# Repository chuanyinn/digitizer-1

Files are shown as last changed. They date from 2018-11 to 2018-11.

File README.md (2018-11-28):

# Digitzer
[Hardware](https://github.com/nupole/digitizer/tree/rev/hw) and [firmware](https://github.com/nupole/digitizer/tree/rev/fw) prototyping of a multichannel 8-bit, 100 MS/s digitizer.

## Features
- Two 1 V<sub>pp</sub> single-ended input channels
- Analog band-pass of 10 kHz to 10 MHz
- 8-bit, 100 MS/s ADCs
- Reconfigurable FPGAa
 - 1 kB/channel event buffer
 - Programmable pre and post-trigger sizes (0 to 2.55 &mu;s)
 - Programmable channel trigger thresholds
 - Programmable coincidence window sizes (0 to 2.55 &mu;s)
 - Programmable trigger coincidence value
 - Programmable trigger veto window size (0 to 2.55 &mu;s)
 - 32 I/O connections
 - 1 single-ended coax I/O
 - 4 JTAG connections

## Table of Contents
1. [Features](#features)
2. [Overview](#overview)

## Overview
The digitizer is a 100 mm by 50 mm electronics card with two 1 V<sub>pp</sub> single-ended input channels sampled by an 8-bit, 100 MS/s ADC. Each channels incoming data is written into its own circular buffer, and upon an internal trigger, is block transferred into its own 1 kB event buffer using user-defined pre and post-trigger window sizes ranging from 0 to 2.55 microseconds (0 to 255 bytes respectively). The event buffers are then readout on a parallel backplane interface.

To form an internal coincidence trigger, each input channel generates a user-defined coincidence window (ranging in size from 0 to 2.55 microseconds) by comparing the current ADC sample with a user-defined threshold. These coincidence windows are added and compared with a user-defined coincidence value to generate both a trigger and veto window. The veto window has user-defined size ranging from 0 to 2.55 microseconds and prevents a re-trigger during its duration.

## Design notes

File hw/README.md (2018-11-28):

# Digitizer (Hardware)
[Hardware](https://github.com/nupole/digitizer/tree/rev/hw) prototyping of a multichannel 8-bit, 100 MS/s digitizer.

## Features
 - Two singled ended input channels
 - Low-pass filter designed using current feedback amplifier in a Sallen-Key topology
 - 8-bit, 100 MS/s ADCs
 - Reconfigurable FPGA
  - 32 I/O connections
  - 1 single-ended coax I/O
  - 4 JTAG connections

## Modifications for Rev 0.1
 - [ ] Remove the solder mask covering the analog and trigger inputs
 - [ ] Exchange 4 pin header for a 6 pin header to include 3.3 V and GND from JTAG programmer
 - [ ] Copper fill the entire power plane
 - [ ] Add grounding strips on the front and back copper layers
 - [ ] Remove unused copper trace on the back copper layers
 - [ ] Slow the TCLK from FT232H programmer by bypassing to ground with 10's of pF

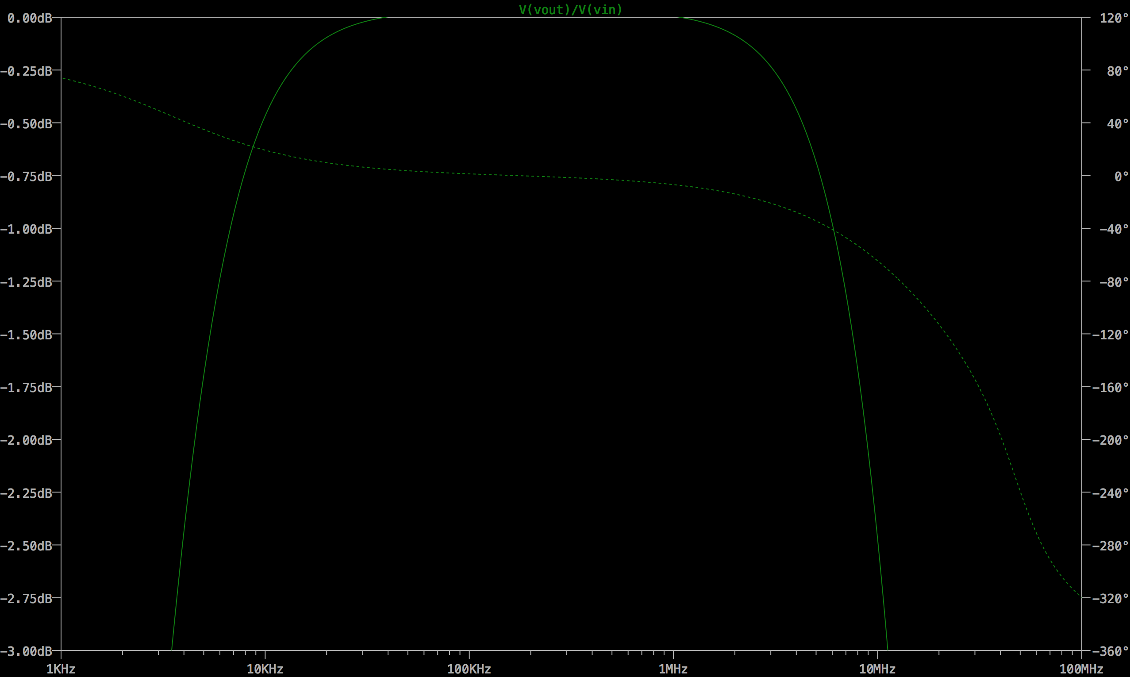
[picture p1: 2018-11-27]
hw/docs/images/Digitizer_AFE_Bandwidth.png

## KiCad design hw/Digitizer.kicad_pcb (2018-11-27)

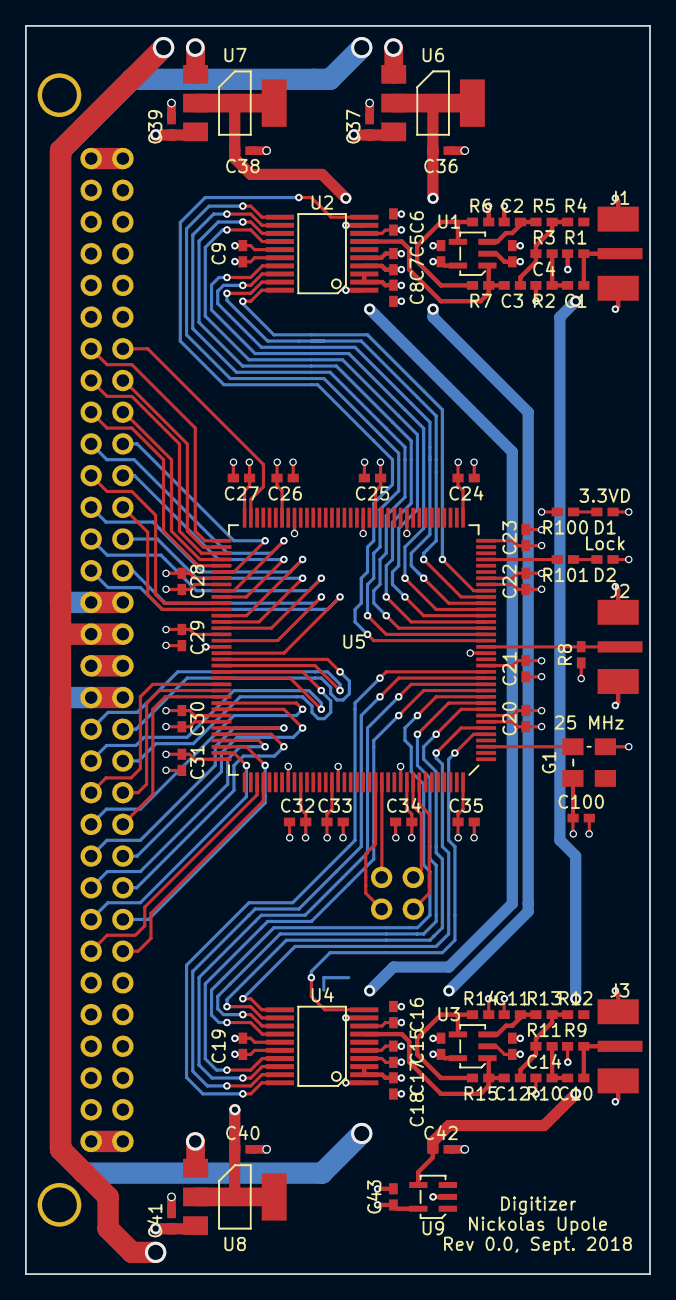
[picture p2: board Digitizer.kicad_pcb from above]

Board: 4 copper layers, 50.0 x 100.0 mm, 77 parts (0 on the bottom side), 81 nets.

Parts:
C1, C10: 1u; 0402
C2, C3, C4, C5, C6, C7, C8, C9, C11, C12, C14, C15, C16, C17, C18, C19, C20, C21, C22, C23, C24, C25, C26, C27, C28, C29, C30, C31, C32, C33, C34, C35, C36, C37, C38, C39, C40, C41, C42, C43, C100: C; 0402
D1, D2: LED; 0402
G1: 510CBA25M0000BAGR; OSC
J1, J2, J3: SMA
J7: Conn_x4; Conn_x4_Straight
J10: Conn_x64; Conn_x64_RightAngle
R1, R2, R8, R9, R10: 50; 0402
R3, R4, R5, R6, R7, R11, R12, R13, R14, R15, R100, R101: R; 0402
U1, U3: AD8014; SOT-23-5
U2, U4: AD9283; SSOP-20
U5: MachXO2; TQFP-144
U6, U7, U8: NCP1117; SOT-223
U9: MIC5270; SOT-23-5

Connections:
/3.3VA: C6.1, C7.1, C16.1, C17.1, C38.1, U2.5, U2.8, U4.5, U4.8, U7.2
/3.3VD: C9.2, C19.2, C20.1, C21.1, C22.1, C23.1, C24.1, C25.1, C26.1, C27.1, C28.2, C29.2, C30.2, C31.2, C32.2, C33.2, C34.2, C35.2, C40.1, C100.1, D1.2, G1.4, U2.15, U4.15, U5.7, U5.16, U5.30, U5.36, U5.37, U5.51, U5.66, U5.72, U5.79, U5.88, U5.102, U5.108, U5.118, U5.123, U5.135, U5.144, U8.2
/5V: C39.1, C41.1, J10.17, J10.48, U7.3, U8.3
/5VA: C5.1, C15.1, C36.1, U1.5, U3.5, U6.2
/12V: C37.1, J10.18, J10.47, U6.3
/25MHz: G1.3, U5.3
/-5VA: C4.2, C14.2, C42.2, U1.2, U3.2, U9.4
/-12V: C43.2, J10.15, J10.50, U9.5
/BP_D0: J10.39, U5.71
/BP_D1: J10.40, U5.74
/BP_D2: J10.41, U5.76
/BP_D3: J10.42, U5.78
/BP_D4: J10.43, U5.82
/BP_D5: J10.44, U5.84
/BP_D6: J10.45, U5.86
/BP_D7: J10.46, U5.89
/BP_D8: J10.51, U5.92
/BP_D9: J10.52, U5.94
/BP_D10: J10.53, U5.97
/BP_D11: J10.54, U5.98
/BP_D12: J10.55, U5.100
/BP_D13: J10.56, U5.104
/BP_D14: J10.57, U5.106
/BP_D15: J10.58, U5.112
/GND: C2.2, C4.1, C5.2, C6.2, C7.2, C8.2, C9.1, C11.2, C14.1, C15.2, C16.2, C17.2, C18.2, C19.1, C20.2, C21.2, C22.2, C23.2, C24.2, C25.2, C26.2, C27.2, C28.1, C29.1, C30.1, C31.1, C32.1, C33.1, C34.1, C35.1, C36.2, C37.2, C38.2, C39.2, C40.2, C41.2, C42.1, C43.1, C100.2, D2.1, G1.2, J1.1, J1.3, J1.4, J1.5, J2.1, J2.3, J2.4, J2.5, J3.1, J3.3, J3.4, J3.5, J10.1, J10.16, J10.32, J10.33, J10.49, J10.64, R1.2, R2.2, R6.1, R8.2, R9.2, R10.2, R14.1, R100.1, U2.1, U2.4, U2.9, U2.16, U4.1, U4.4, U4.9, U4.16, U5.8, U5.18, U5.29, U5.46, U5.53, U5.64, U5.80, U5.90, U5.101, U5.116, U5.124, U5.134, U6.1, U7.1, U8.1, U9.2
/IO7: J10.7, U5.111
/IO8: J10.8, U5.107
/IO9: J10.9, U5.105
/IO10: J10.10, U5.103
/IO11: J10.11, U5.99
/IO12: J10.12, U5.96
/IO13: J10.13, U5.95
/IO14: J10.14, U5.93
/IO19: J10.19, U5.91
/IO20: J10.20, U5.87
/IO21: J10.21, U5.85
/IO22: J10.22, U5.83
/IO23: J10.23, U5.81
/IO24: J10.24, U5.77
/IO25: J10.25, U5.75
/IO26: J10.26, U5.73
/LOCK: R101.2, U5.33
/Sig1: C3.2, R7.2, U1.1, U2.7
/Sig1_CLK: U2.10, U5.20
/Sig1_D0: U2.20, U5.28
/Sig1_D1: U2.19, U5.27
/Sig1_D2: U2.18, U5.26
/Sig1_D3: U2.17, U5.25
/Sig1_D4: U2.14, U5.24
/Sig1_D5: U2.13, U5.23
/Sig1_D6: U2.12, U5.22
/Sig1_D7: U2.11, U5.21
/Sig2: C12.2, R15.2, U3.1, U4.7
/Sig2_CLK: U4.10, U5.5
/Sig2_D0: U4.20, U5.15
/Sig2_D1: U4.19, U5.14
/Sig2_D2: U4.18, U5.13
/Sig2_D3: U4.17, U5.12
/Sig2_D4: U4.14, U5.11
/Sig2_D5: U4.13, U5.10
/Sig2_D6: U4.12, U5.9
/Sig2_D7: U4.11, U5.6
/TCK: J7.3, U5.131
/TDI: J7.2, U5.136
/TDO: J7.1, U5.137
/TMS: J7.4, U5.130
/Trig: J2.2, R8.1, U5.19
unnamed: C1.1, J1.2, R1.1
unnamed: C1.2, R2.1, R3.1
unnamed: C2.1, R5.2, U1.3
unnamed: C3.1, R3.2, R4.2, R5.1
unnamed: C8.1, U2.2, U2.3
unnamed: C10.1, J3.2, R9.1
unnamed: C10.2, R10.1, R11.1
unnamed: C11.1, R13.2, U3.3
unnamed: C12.1, R11.2, R12.2, R13.1
unnamed: C18.1, U4.2, U4.3
unnamed: D1.1, R100.2
unnamed: D2.2, R101.1
unnamed: R6.2, R7.1, U1.4
unnamed: R14.2, R15.1, U3.4

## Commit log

2018-11-20 Initial commit of TRIGMGR (trigmgr.vhdl)
    Added a TRIGMGR (trigmgr.vhdl) composed of the following entities:
    - COINWIN (coinwin.vhdl): generates a user-defined coincidence window
    when the ADC value reads below a user-defined threshold
    - COINDETR (coindetr.vhdl): generates a 1 clock cycle pulse when a
    user-defined number of coincidence windows overlap
    - TRIG (trig.vhdl): generates a 1 clock cycle pulse and a user defined
    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
2018-11-27 Initial hardware commit
    The hardware commit contains the following useful items
    - Vendor datasheets and documentation pertaining to both firmware and hardware
    - KiCad source files including schematic and footprint libraries
    - LTSpice simulation files for an estimate of the analog front end bandwidth (from Bode plot)
    [Digitizer-B.Cu.gbl, Digitizer-B.Mask.gbs, Digitizer-B.SilkS.gbo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]
